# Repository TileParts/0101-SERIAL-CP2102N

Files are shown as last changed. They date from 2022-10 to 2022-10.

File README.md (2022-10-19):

0101-SERIAL-CP2102N
==========

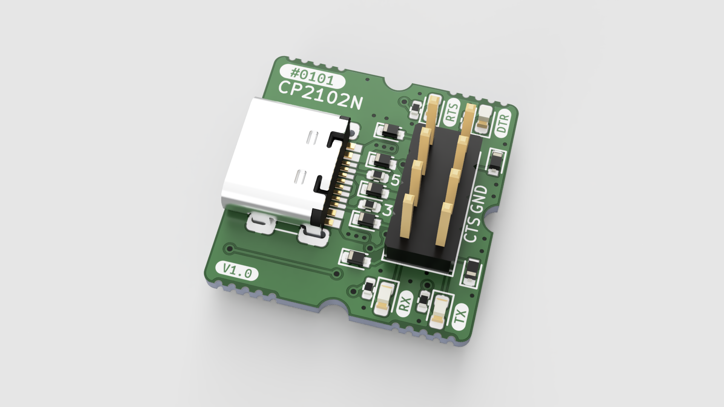
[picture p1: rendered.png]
0101-SERIAL-CP2102N


基于 CP2102N 的 USB-UART 转接器，并且附带 ESP32 兼容的自动烧录电路。

## 配置

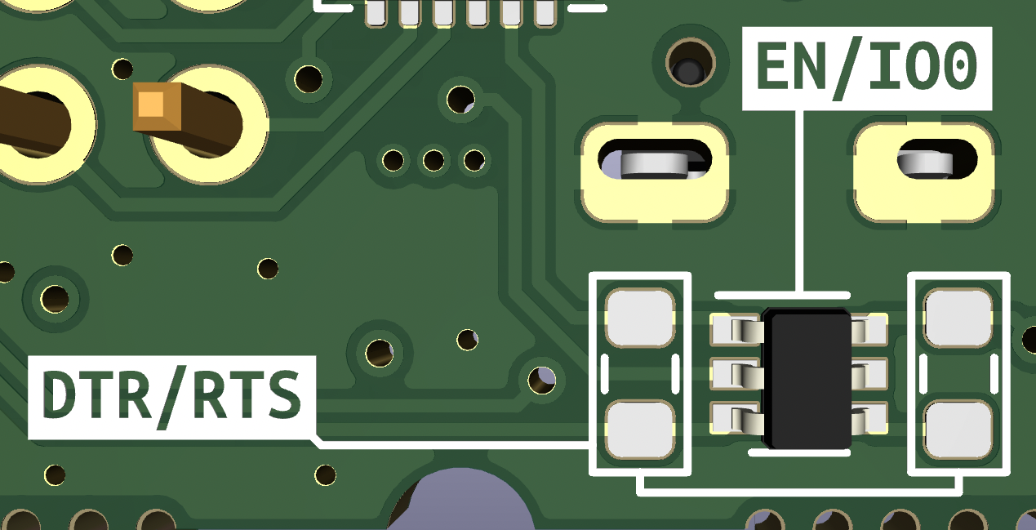
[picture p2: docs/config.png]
配置


SERIAL-CP2102N 背面预留了可配置的电路，可将 DTR/RTS 更改为用于 ESP32 自动烧录的 EN/IO0 功能。具体如下：

| 功能 | R8/R9 | Q1 |
|-----|-----|-----|
| 用作 DTR/RTS | 焊接 0Ω 0603 电阻 | 留空 |
| 用作 ESP32 烧录 | 留空 | 焊接 PUMH4,115 |

## 协议

[CERN-OHL-P-2.0](LICENSE)

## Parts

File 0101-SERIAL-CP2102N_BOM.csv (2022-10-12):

Manufacturer | Comment | Designator | Footprint | Quantity | PartNumber | Supplier
SAMSUNG | 0.1uF | C3 C4 | C_0402_1005Metric | 2 | C1525 | JLC
SAMSUNG | 4.7uF | C1 C2 | C_0402_1005Metric | 2 | C23733 | JLC
EVERLIGHT | LED_BLU | D3 | LED_0603_1608Metric | 1 | C72041 | JLC
EVERLIGHT | LED_YEL | D1 D2 | LED_0603_1608Metric | 2 | C72038 | JLC
KENTO | LED_RED | D4 | LED_0603_1608Metric | 1 | C2286 | JLC
UniOhm | 1K | R3 | R_0402_1005Metric | 1 | C11702 | JLC
UniOhm | 1.5K | R12 R13 R14 R15 | R_0402_1005Metric | 4 | C25867 | JLC
UniOhm | 5.1K | R4 R5 | R_0402_1005Metric | 2 | C25905 | JLC
UniOhm | 0R(NC) | R8 R9 | R_0603_1608Metric | 2 | C21189 | JLC
LRC | LESD5Z5.0CT1G | D5 D6 D7 D8 D9 D10 D11 | D_SOD-523 | 7 | C136167 | JLC-EXT
HRO | USB-C | J1 | HRO_TYPE-C-31-M-12 | 1 | C165948 | JLC-EXT
SILICON LABS | CP2102N-A02-GQFN24 | U1 | QFN-24-1EP_4x4mm_P0.5mm_EP2.6x2.6mm | 1 | C969151 | JLC-EXT
UniOhm | 22.1K | R1 | R_0402_1005Metric | 1 | C43473 | JLC-EXT
UniOhm | 47.5K | R2 | R_0402_1005Metric | 1 | C25896 | JLC-EXT
Nexperia | PUMH4,115 | Q1 Q1 | SOT-363_SC-70-6 | 2 | C455002 | JLC-EXT

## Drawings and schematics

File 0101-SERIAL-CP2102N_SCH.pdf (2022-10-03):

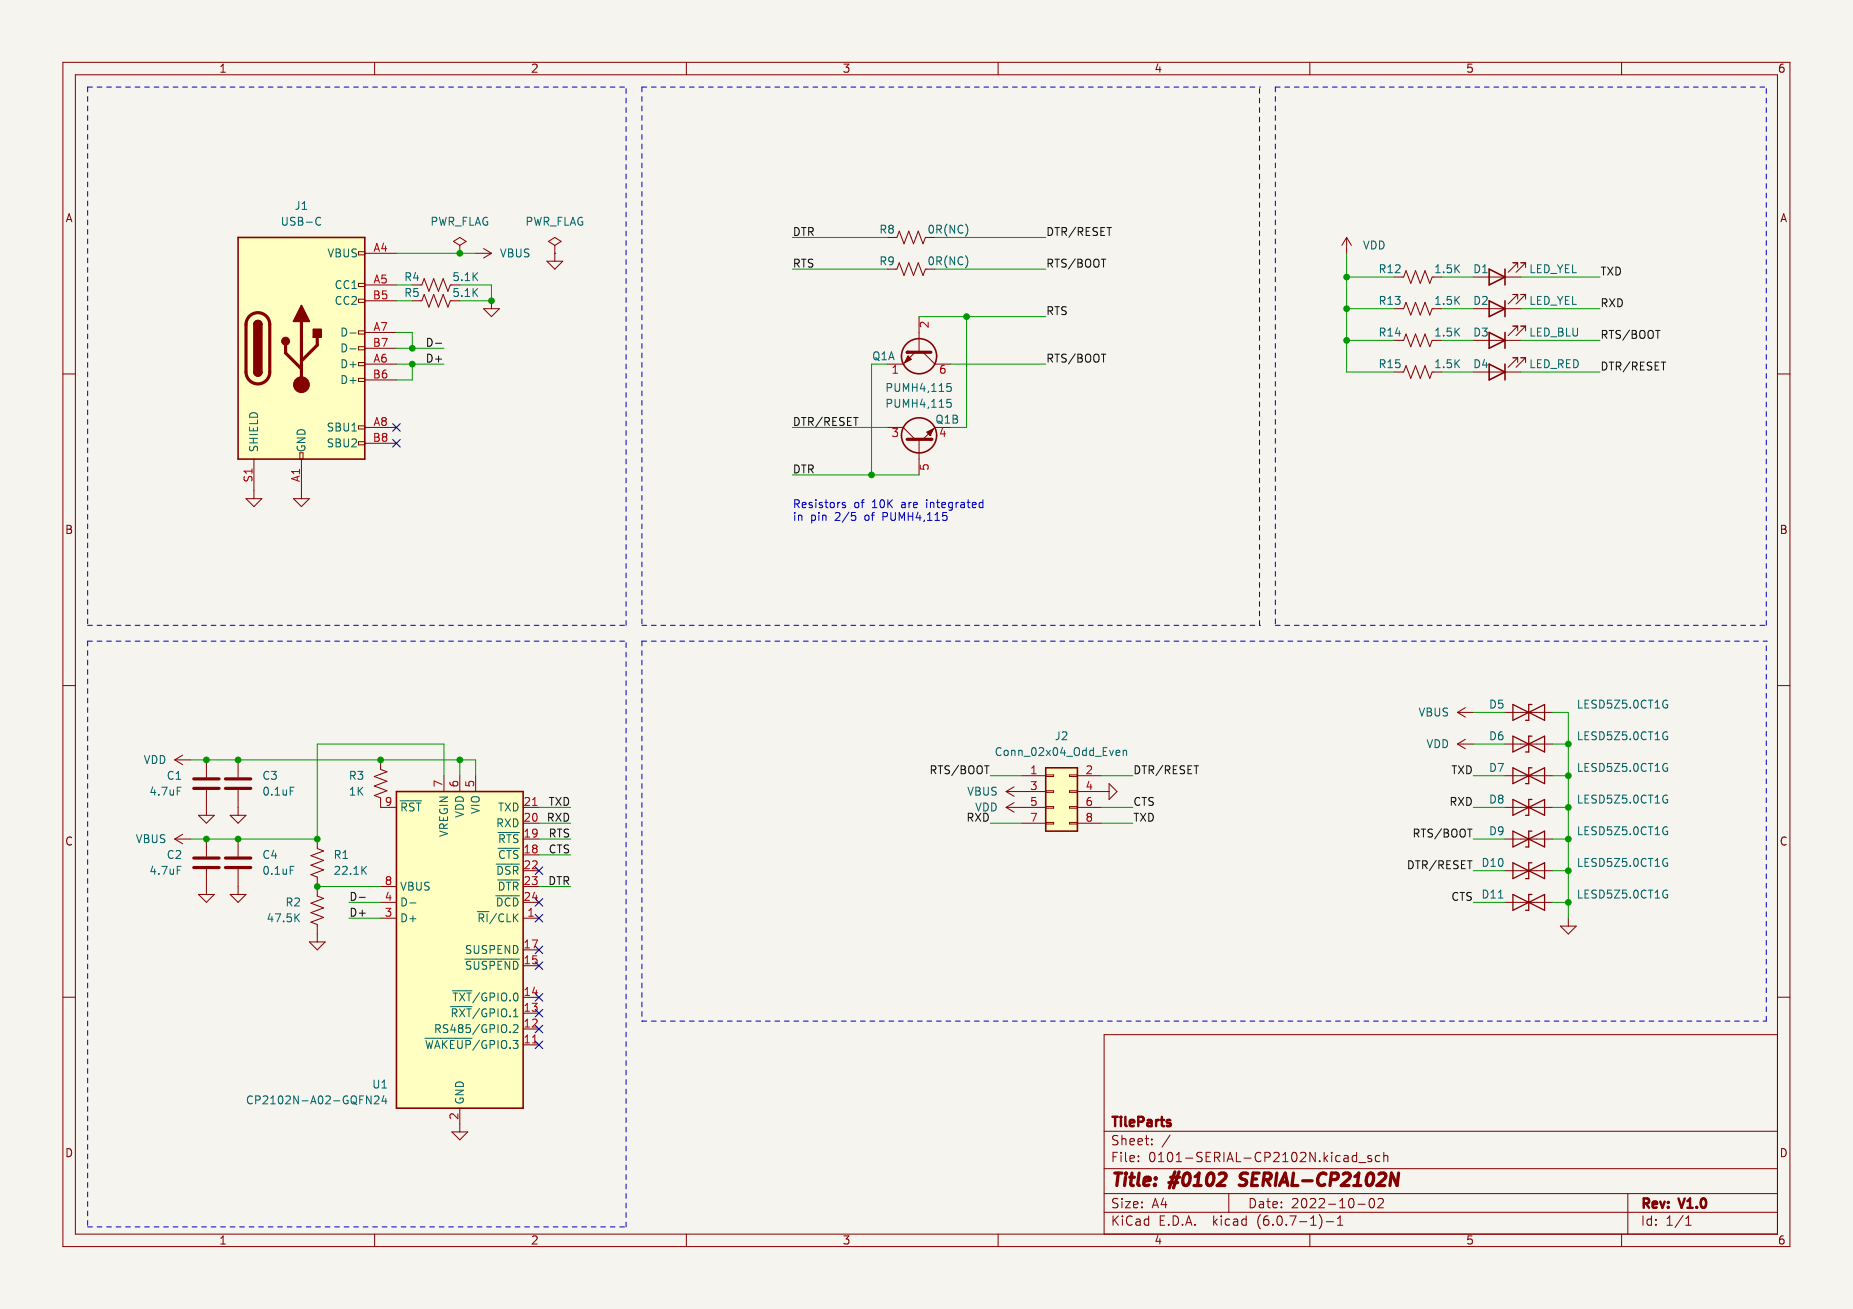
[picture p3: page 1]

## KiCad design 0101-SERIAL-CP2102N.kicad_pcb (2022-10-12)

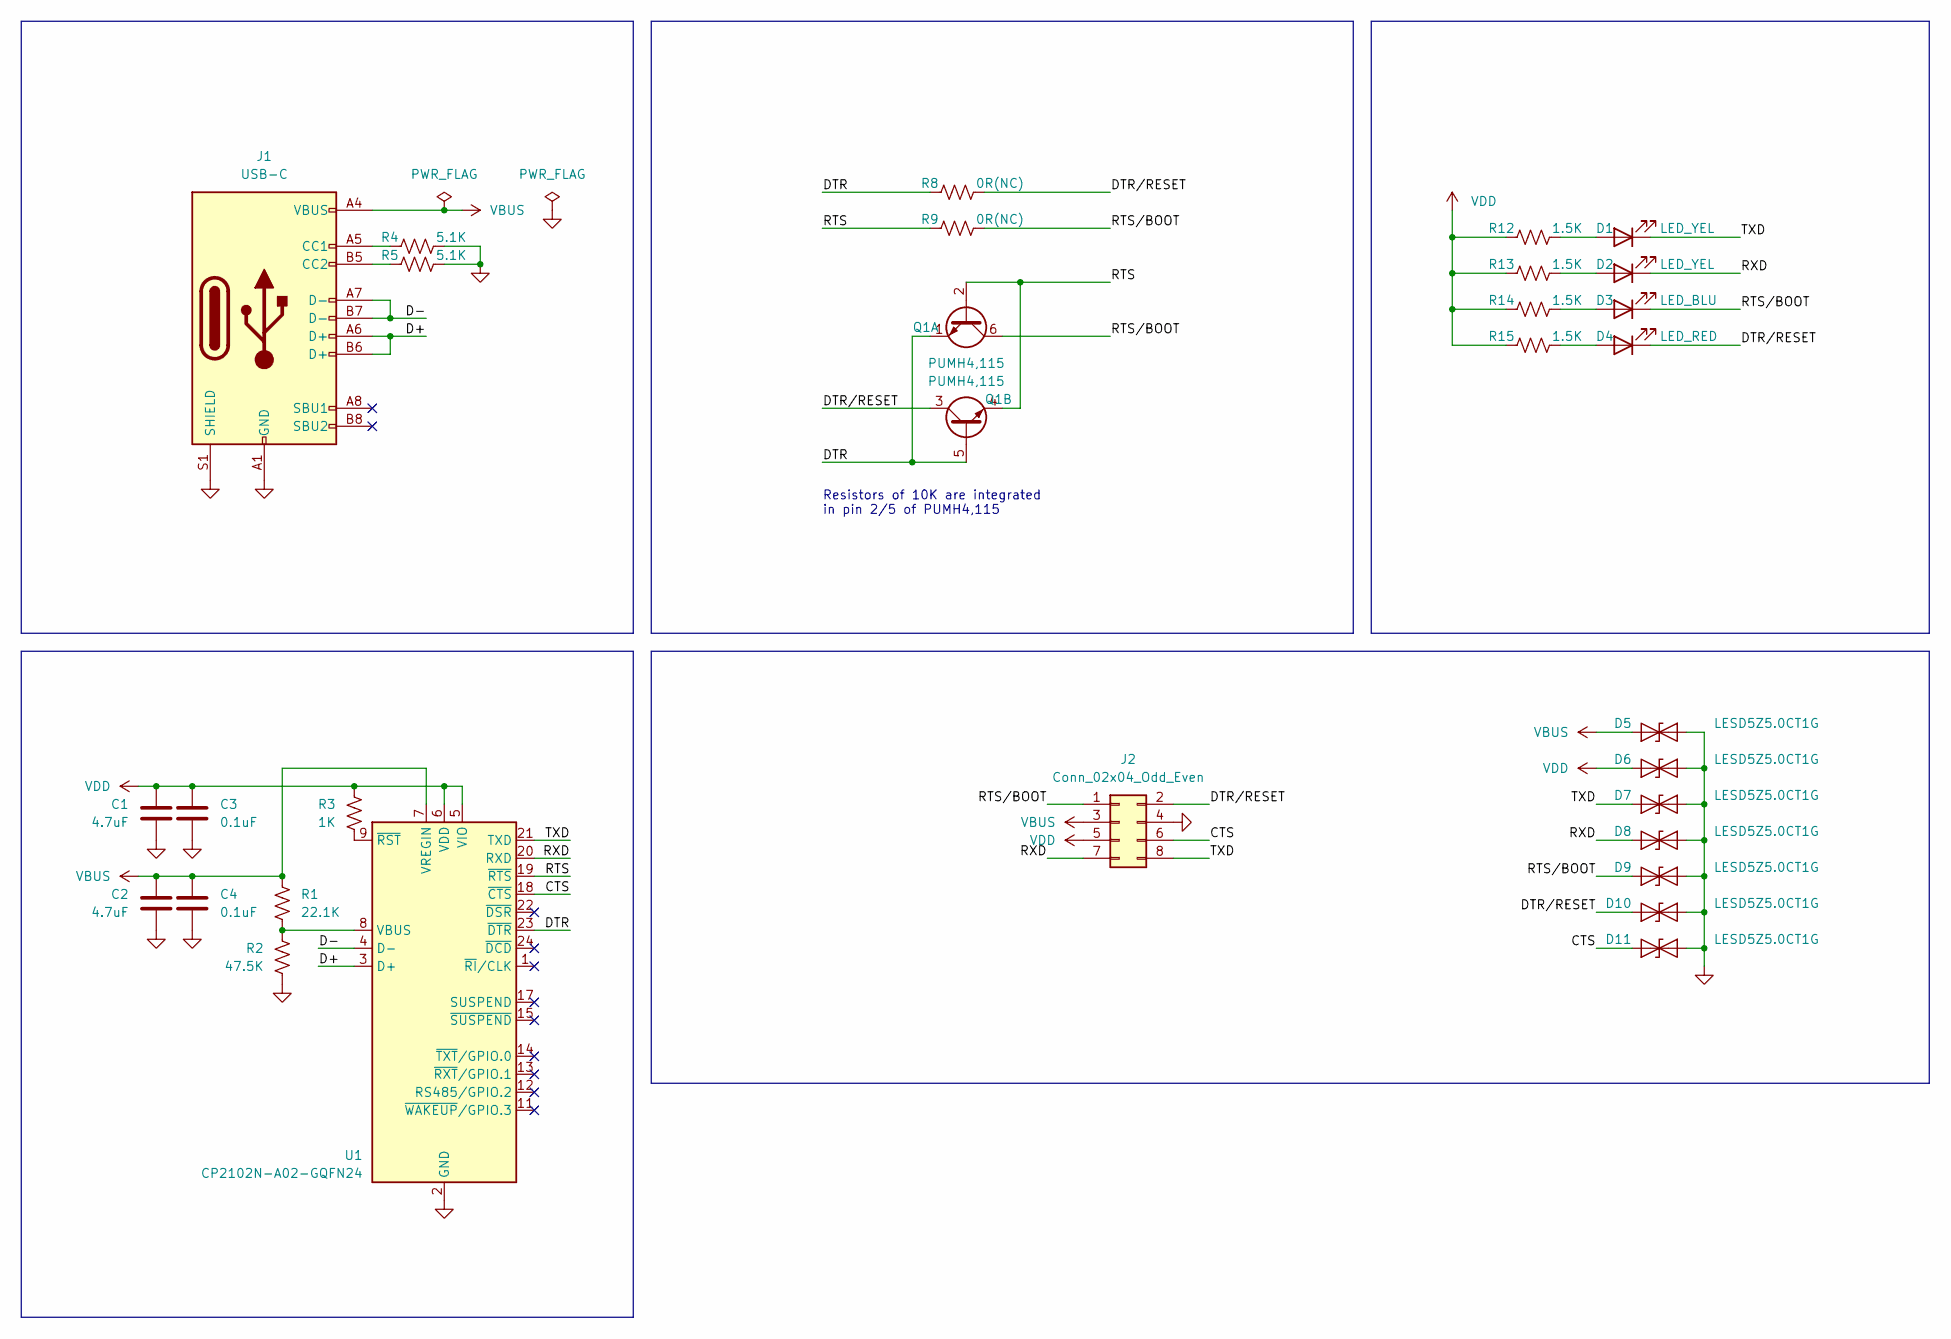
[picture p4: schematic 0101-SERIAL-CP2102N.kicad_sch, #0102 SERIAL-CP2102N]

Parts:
C1, C2: 4.7uF; C_0402_1005Metric; PartNumber C23733
C3, C4: 0.1uF; C_0402_1005Metric; PartNumber C1525
D1, D2: LED_YEL; LED_0603_1608Metric; PartNumber C72038
D3: LED_BLU; LED_0603_1608Metric; PartNumber C72041
D4: LED_RED; LED_0603_1608Metric; PartNumber C2286
D5, D6, D7, D8, D9, D10, D11: LESD5Z5.0CT1G; D_SOD-523; PartNumber C136167
J1: USB-C; HRO_TYPE-C-31-M-12; PartNumber C165948
J2: Conn_02x04_Odd_Even; PinHeader_2x04_P2.54mm_Vertical
Q1: PUMH4,115; SOT-363_SC-70-6; PartNumber C455002
R1: 22.1K; R_0402_1005Metric; PartNumber C43473
R2: 47.5K; R_0402_1005Metric; PartNumber C25896
R3: 1K; R_0402_1005Metric; PartNumber C11702
R4, R5: 5.1K; R_0402_1005Metric; PartNumber C25905
R8, R9: 0R(NC); R_0603_1608Metric; PartNumber C21189
R12, R13, R14, R15: 1.5K; R_0402_1005Metric; PartNumber C25867
U1: CP2102N-A02-GQFN24; QFN-24-1EP_4x4mm_P0.5mm_EP2.6x2.6mm; PartNumber C969151

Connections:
/CTS: D11.2 (A2), J2.6, U1.18 (~CTS)
/D+: J1.A6 (D+), J1.B6 (D+), U1.3 (D+)
/D-: J1.A7 (D-), J1.B7 (D-), U1.4 (D-)
/DTR: Q1.1 (E1), Q1.5 (B2), R8.1, U1.23 (~DTR)
/DTR/RESET: D4.1 (K), D10.2 (A2), J2.2, Q1.3 (C2), R8.2
/RTS: Q1.2 (B1), Q1.4 (E2), R9.1, U1.19 (~RTS)
/RTS/BOOT: D3.1 (K), D9.2 (A2), J2.1, Q1.6 (C1), R9.2
/RXD: D2.1 (K), D8.2 (A2), J2.7, U1.20 (RXD)
/TXD: D1.1 (K), D7.2 (A2), J2.8, U1.21 (TXD)
GND: C1.2, C2.2, C3.2, C4.2, D5.1 (A1), D6.1 (A1), D7.1 (A1), D8.1 (A1), D9.1 (A1), D10.1 (A1), D11.1 (A1), J1.A1 (GND), J1.A12 (GND), J1.B1 (GND), J1.B12 (GND), J1.S1 (SHIELD), J2.4, R2.2, R4.2, R5.2, U1.2 (GND), U1.25 (GND)
unnamed: D1.2 (A), R12.2
unnamed: D2.2 (A), R13.2
unnamed: D3.2 (A), R14.2
unnamed: D4.2 (A), R15.2
unnamed: J1.A5 (CC1), R4.1
unnamed: J1.B5 (CC2), R5.1
unnamed: R1.2, R2.1, U1.8 (VBUS)
unnamed: R3.2, U1.9 (~RST)
VBUS: C2.1, C4.1, D5.2 (A2), J1.A4 (VBUS), J1.A9 (VBUS), J1.B4 (VBUS), J1.B9 (VBUS), J2.3, R1.1, U1.7 (VREGIN)
VDD: C1.1, C3.1, D6.2 (A2), J2.5, R3.1, R12.1, R13.1, R14.1, R15.1, U1.5 (VIO), U1.6 (VDD)

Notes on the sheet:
Resistors of 10K are integrated in pin 2/5 of PUMH4,115

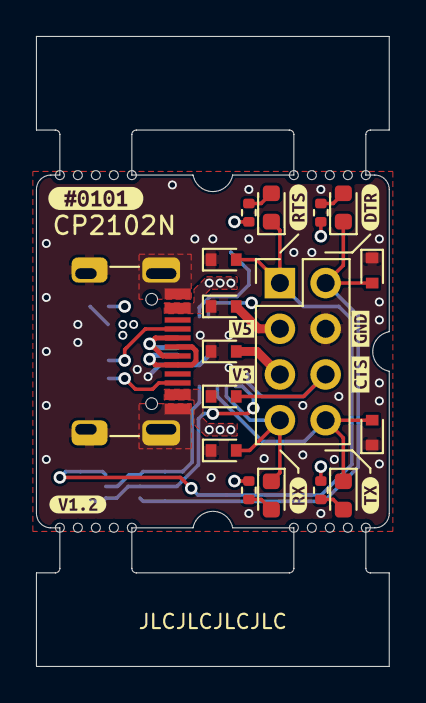
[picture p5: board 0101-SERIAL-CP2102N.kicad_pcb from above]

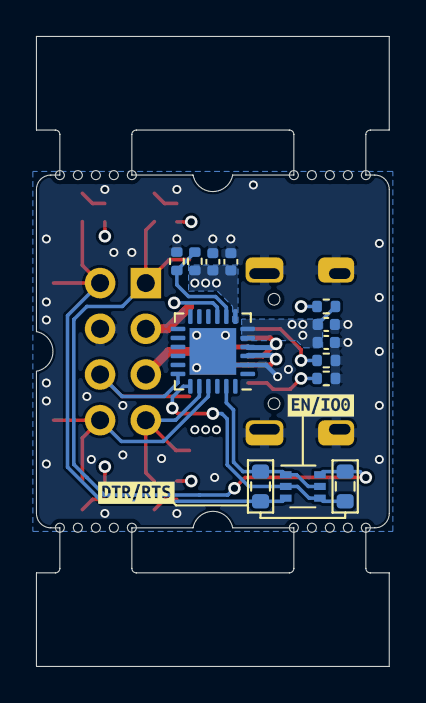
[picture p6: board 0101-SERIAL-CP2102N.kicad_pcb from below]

Board: 4 copper layers, 19.6 x 35.0 mm, 42 parts (15 on the bottom side), 20 nets.

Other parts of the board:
kibuzzard-633A4DBF: G***; kibuzzard-633A4DBF
kibuzzard-633A4E09: G***; kibuzzard-633A4E09
kibuzzard-6344EE6E: G***; kibuzzard-6344EE6E
kibuzzard-6344EE61: G***; kibuzzard-6344EE61
kibuzzard-6344EEF9: G***; kibuzzard-6344EEF9
kibuzzard-6344EF12: G***; kibuzzard-6344EF12
kibuzzard-63351A8A: G***; kibuzzard-63351A8A
kibuzzard-63353A29: G***; kibuzzard-63353A29
kibuzzard-63353A37: G***; kibuzzard-63353A37
kibuzzard-6339534D: G***; kibuzzard-6339534D
kibuzzard-6346685F: G***; kibuzzard-6346685F
kibuzzard-63395349: G***; kibuzzard-63395349

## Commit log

2022-09-29 Create CP2102N
    [0101-SERIAL-CP2102N.kicad_pcb, 0101-SERIAL-CP2102N.kicad_sch]
2022-10-02 Done PCB
    [0101-SERIAL-CP2102N.kicad_pcb, 0101-SERIAL-CP2102N.kicad_sch]
2022-10-02 Finish BOM
    [0101-SERIAL-CP2102N.kicad_pcb, 0101-SERIAL-CP2102N.kicad_sch]
2022-10-03 Finish silks
    [0101-SERIAL-CP2102N.kicad_pcb]
2022-10-03 Output docs
    [0101-SERIAL-CP2102N-Bottom_Cu.gbr, 0101-SERIAL-CP2102N-Bottom_Mask.gbr, 0101-SERIAL-CP2102N-Bottom_Paste.gbr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]
2022-10-03 Adjust position of LEDs
    [0101-SERIAL-CP2102N.kicad_pcb]
2022-10-03 Add craft edge
    [0101-SERIAL-CP2102N.kicad_pcb]
2022-10-03 Update docs
    [0101-SERIAL-CP2102N-Bottom_Cu.gbr, 0101-SERIAL-CP2102N-Bottom_Mask.gbr, 0101-SERIAL-CP2102N-Bottom_Paste.gbr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]
2022-10-04 Update render image
    [0101-SERIAL-CP2102N.kicad_pcb]
2022-10-06 Update package of USB-C
    [0101-SERIAL-CP2102N.kicad_pcb]
2022-10-07 Tune power tracks
    [0101-SERIAL-CP2102N.kicad_pcb]
2022-10-11 Move CC 5.1K pull-down resistors to B.Cu
    * so that they can be soldered together with CP2102N
    [0101-SERIAL-CP2102N.kicad_pcb]
2022-10-11 Make silks better
    [0101-SERIAL-CP2102N.kicad_pcb]
2022-10-12 Update MF docs V1.1
    [0101-SERIAL-CP2102N-Bottom_Cu.gbr, 0101-SERIAL-CP2102N-Bottom_Mask.gbr, 0101-SERIAL-CP2102N-Bottom_Paste.gbr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]
2022-10-12 Fix outline
    [0101-SERIAL-CP2102N-Bottom_Cu.gbr, 0101-SERIAL-CP2102N-Bottom_Mask.gbr, 0101-SERIAL-CP2102N-Bottom_Paste.gbr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]
